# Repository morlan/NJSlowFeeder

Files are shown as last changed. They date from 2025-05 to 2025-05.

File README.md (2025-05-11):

# NJSlowFeeder

This is a slowfeeder for feeding coffee beans into a grinder. It is designed to be 3D printed and assembled with basic mechanical and electrical tools (hex driver, soldering iron, wire strippers).

## Updates:
V1.2 is out. See Issues for additional adaptors or to request additional functionality.\
Development is actively occuring, the main discussion channel is on the Gaggiuino Discord. 

## V1.2
V1.2 introduces a microcontroller (with BLE/Wifi), PWM motor controller, and load cell compatiblity while maintaining the great battery life of V1.1.\
V1.2 CAD is stable. See Issues to request new adaptors or other features.\
V1.2 Code is very much a proof of concept, and under development.\
BOM at [this link](https://docs.google.com/spreadsheets/d/11zUR7dkBkgdKcGbynbE2zPVb8PsdSGaQEwi6_OAgMBY/edit?usp=sharing).
### Demo Video
SlowFeeder V1.2 Demo (https://www.youtube.com/watch?v=54PZubX1fOw)

### Working Functions:
1. Variable speed control (hold up/down once wheel is turning)
2. On/Off control of wheel
3. Loadcell reading and setup taring (basic)
4. Deepsleep (works, but currently higher draw than expected with the HX711 for some reason)

### Planned Functions:
- [ ] WebUI for parameter control
- [ ] PoopCode :tm: - Precise single dosing of beans (for filling vials or grinding)

### Getting Started with V1.2 Code
1. Install VSCode
2. Clone this repo
3. Open the NJSlowfeeder.code-workspace file
   - This should install all required dependencies
4. Open folder in Platformio extension (if not already selected)
5. Choose the MCU you have in the Platformio Project Tasks section, plug MCU into computer, click upload
   - If this fails, try holding the boot button as you plug the MCU into the computer
6. Done

## V1.1 
V1.1 uses a fully analog approach to slowfeeding and does not include a microcontroller.\
V1.1 is unlikely to receive further updates. An analog V1.2 can be made with some tweaks to the BOM.\
Speed is set using a regulator of user choice (good options listed in BOM) and is not easily adjustable on the fly. \
See the V1.1 folder in CAD_Models for more details.\
BOM at [this link](https://docs.google.com/spreadsheets/d/11zUR7dkBkgdKcGbynbE2zPVb8PsdSGaQEwi6_OAgMBY/edit?usp=sharing).

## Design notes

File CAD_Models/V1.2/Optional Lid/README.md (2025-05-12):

# Lid

A more integrated lid is planned for release in V1.2.x or V1.3. Currently, the V1.1 version from discord user mor_177012 can be used.

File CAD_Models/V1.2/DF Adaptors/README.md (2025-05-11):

# DF Compatibility
By grinder, (XXmm) shows ID or OD dimension of feature.\
Recommended to measure your grinder, especially if it's not listed or you're unsure.\
See DFModelsImage.png for a visual list of all DF models.

## DF83
DF83V with bellows (70mm) or popcorn ring (56mm) - DF83Vring_v1_2

## DF64
There are a lot of variants of the DF64. If yours isn't listed, please contribute an image in an issue with the measurement so it can be added.\
DF64 with popcorn ring (56mm) - DF83Vring_V1_2\
DF64 without bellows or anti-popcorn ring (76mm) - DF64nopop_ring_v1_2\
DF64 Gen 2 with popcorn ring (56mm) - DF83Vring_V1_2\
DF64V V1 with bellows (56mm) - DF54Ring_V1_2

## DF54
DF54 with bellows (56mm) - DF54Ring_v1_2\
DF54 with popcorn ring (56mm) - DF83Vring_v1_2\
Note: you cannot use a DF54 with both bellows and popcorn ring since they're the same dimension.

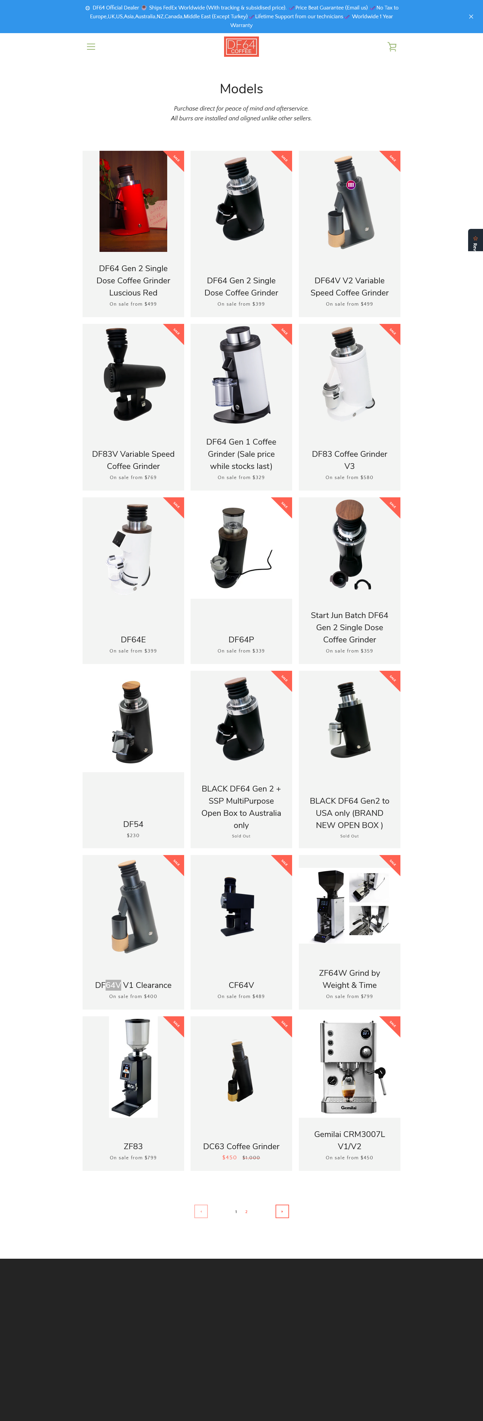
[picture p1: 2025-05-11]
CAD_Models/V1.2/DF Adaptors/DFModelsImage.png

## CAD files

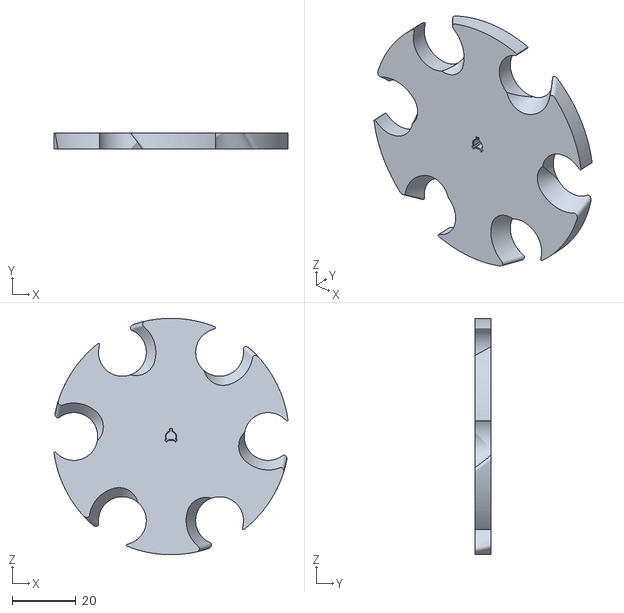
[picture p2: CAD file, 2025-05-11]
CAD_Models/V1.2/Alternate Wheels/slowfeed_wheel_6hole_nj_v1_2_.stl
73.5 x 5.00 x 74.2

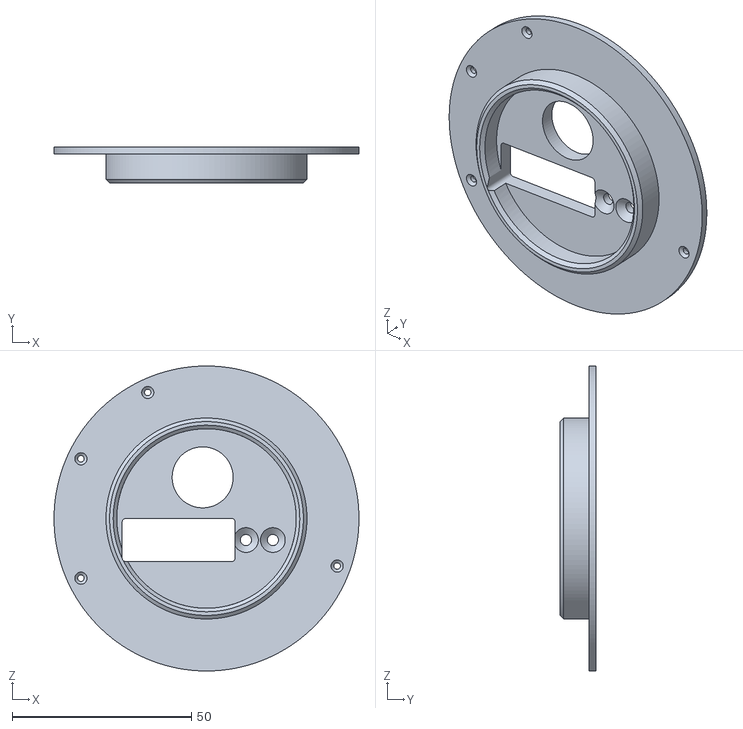
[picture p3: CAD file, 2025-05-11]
CAD_Models/V1.2/DF Adaptors/slowfeed_df54ring_bellows_v1_2.stl
85.0 x 10.0 x 85.0

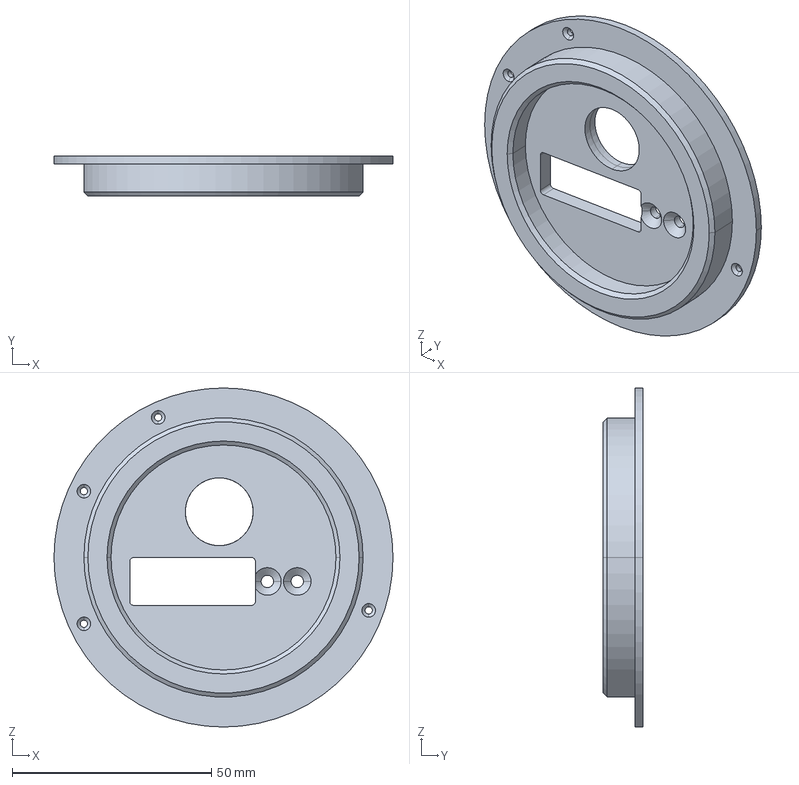
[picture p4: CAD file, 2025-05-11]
CAD_Models/V1.2/Generic Adaptor Ring (step file)/slowfeed_df83vring_v1_2.stp
85.0 x 10.0 x 85.0 mm

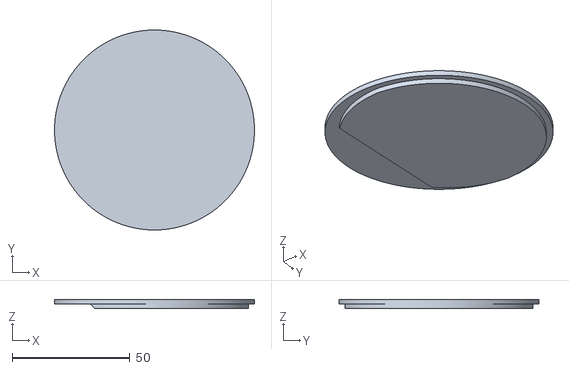
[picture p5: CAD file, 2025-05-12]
CAD_Models/V1.2/Optional Lid/slowfeed_nj_v1_1_lid_mor.stl
85.0 x 84.9 x 4.00

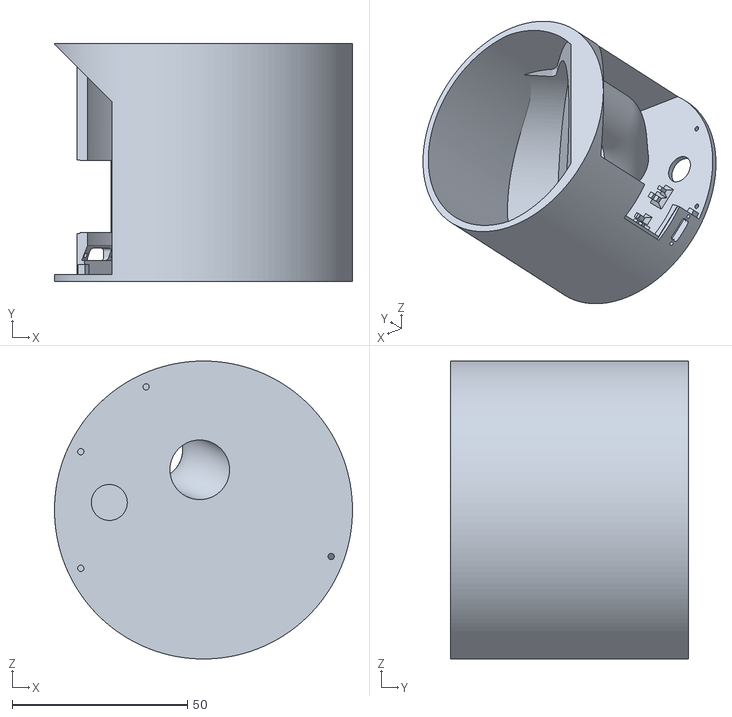
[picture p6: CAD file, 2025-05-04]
CAD_Models/V1.2/slowfeed_nj_v1_2_xiao.stl
85.0 x 68.0 x 85.0

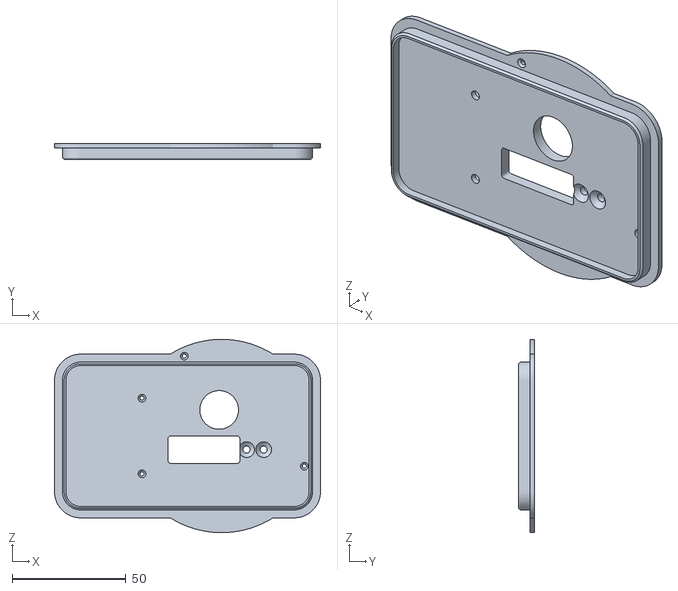
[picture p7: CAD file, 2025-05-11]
CAD_Models/V1.2/Timemore Adaptors/slowfeed_064s_ring_v1_2.stl
117.0 x 7.00 x 85.0

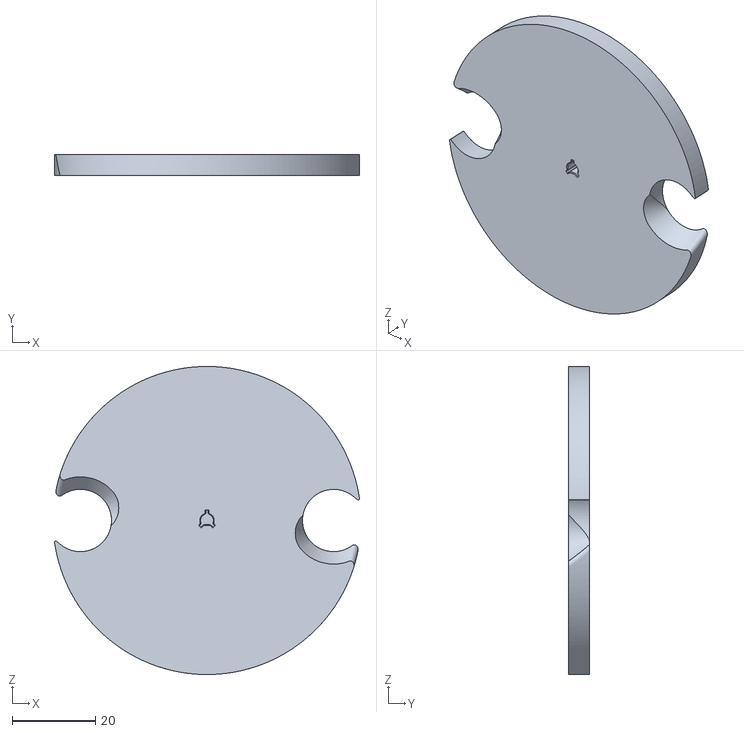
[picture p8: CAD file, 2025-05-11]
CAD_Models/V1.2/Alternate Wheels/slowfeed_wheel_2hole_nj_v1_2_.stl
73.5 x 5.00 x 74.2

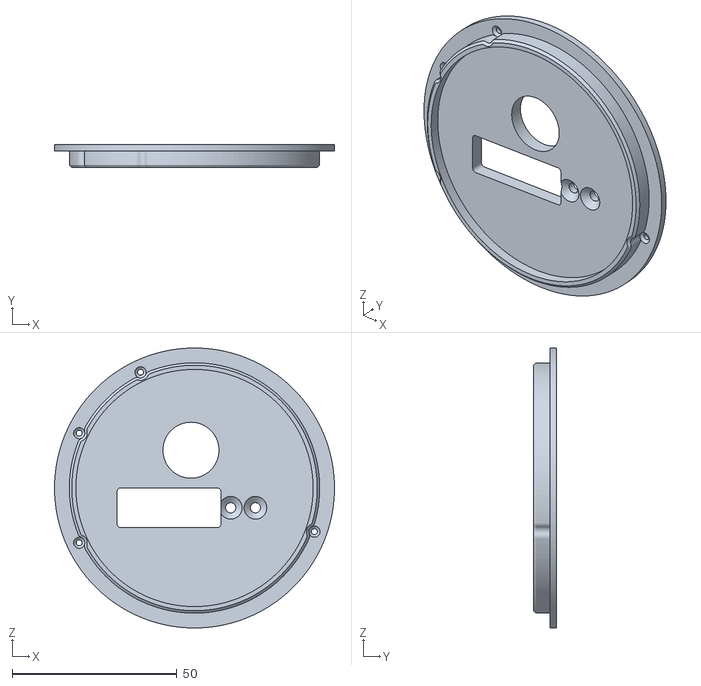
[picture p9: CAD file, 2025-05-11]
CAD_Models/V1.2/DF Adaptors/slowfeed_df64nopop_ring_v1_2.stl
85.0 x 7.00 x 85.0

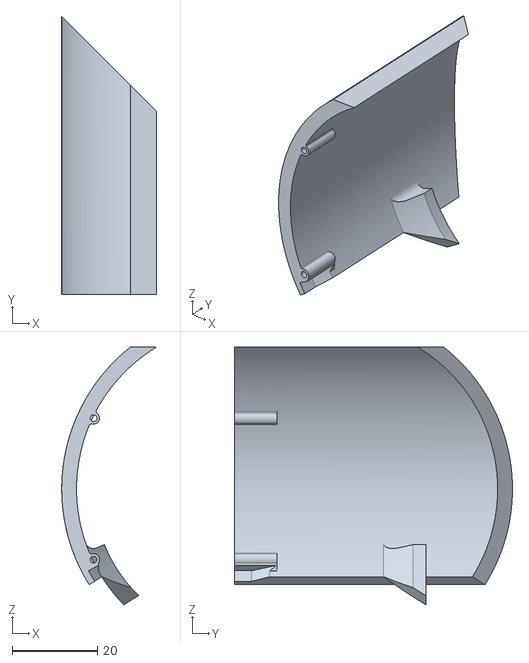
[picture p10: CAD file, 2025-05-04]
CAD_Models/V1.2/slowfeed_door_nj_v1_2.stl
22.3 x 65.4 x 60.6

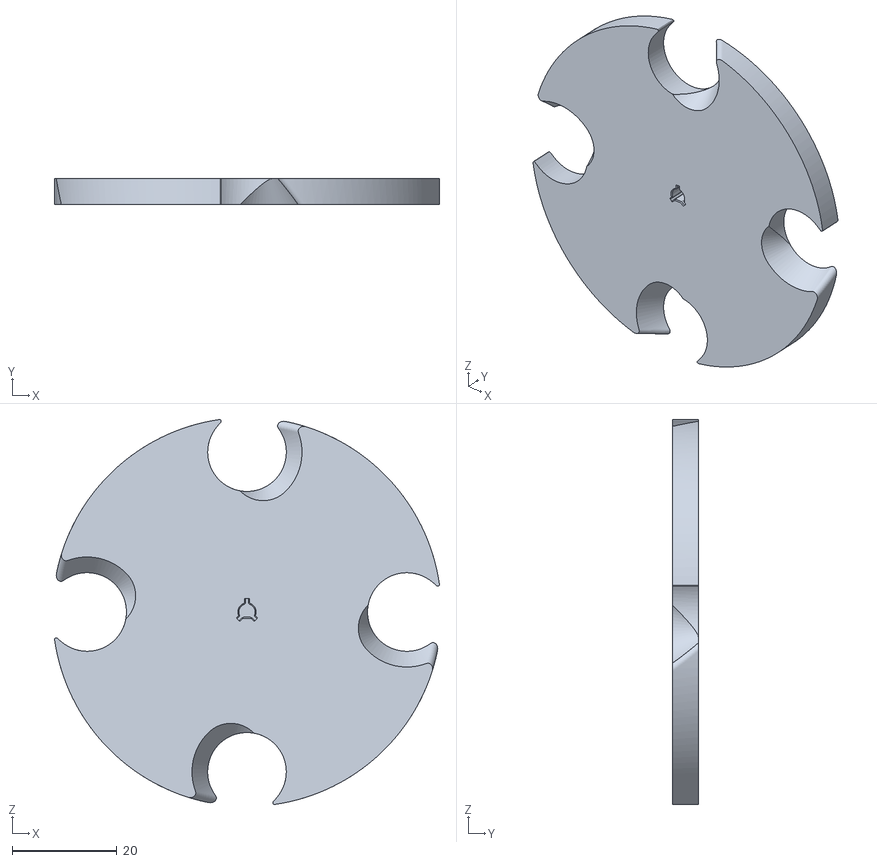
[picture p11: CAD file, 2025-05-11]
CAD_Models/V1.2/Alternate Wheels/slowfeed_wheel_4hole_nj_v1_2_.stl
73.5 x 5.00 x 73.5

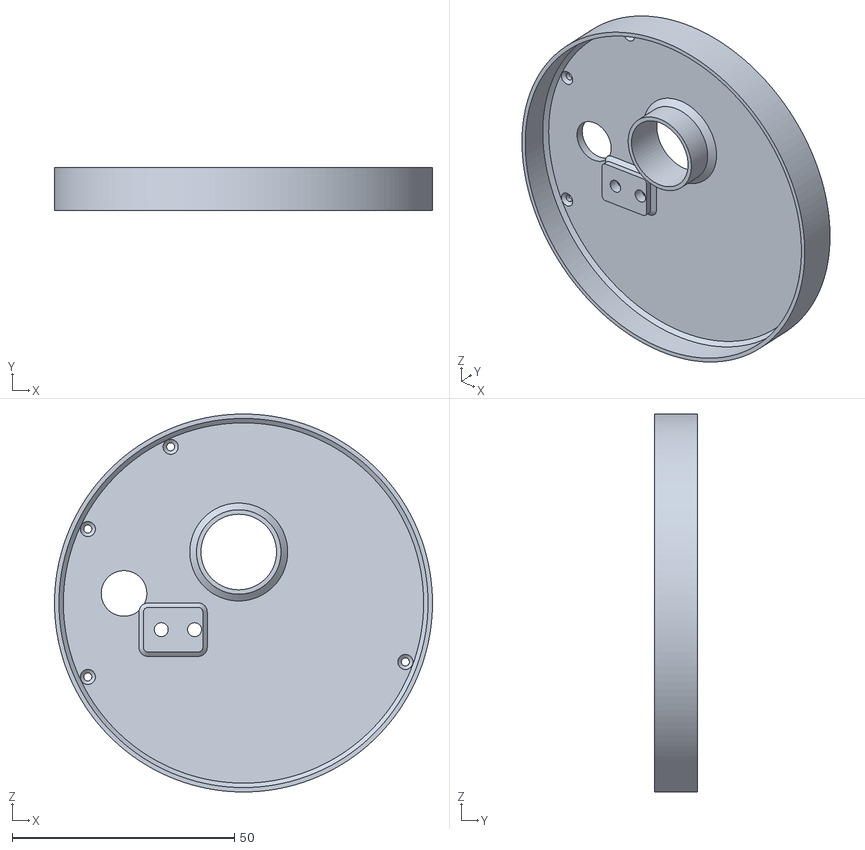
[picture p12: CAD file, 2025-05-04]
CAD_Models/V1.2/slowfeed_loadcellring_v1_2.stl
85.0 x 9.75 x 85.0

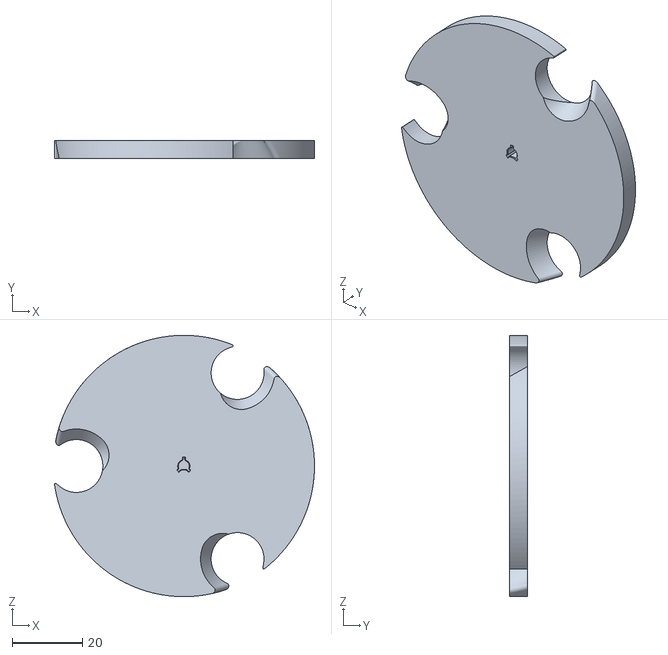
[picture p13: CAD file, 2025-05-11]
CAD_Models/V1.2/Alternate Wheels/slowfeed_wheel_3hole_nj_v1_2_.stl
73.8 x 5.00 x 74.2

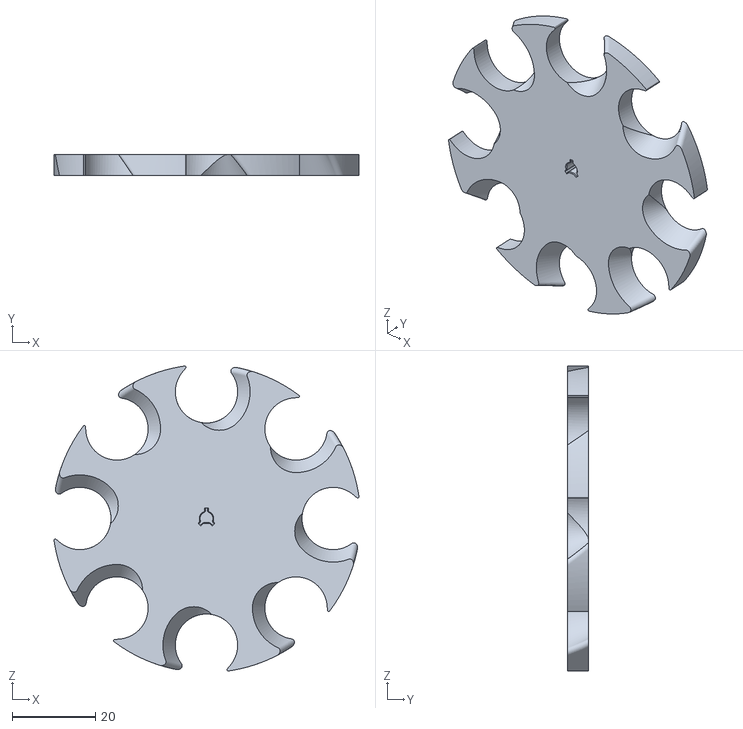
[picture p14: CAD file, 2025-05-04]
CAD_Models/V1.2/slowfeed_wheel_8hole_nj_v1_2.stl
73.5 x 5.00 x 73.5

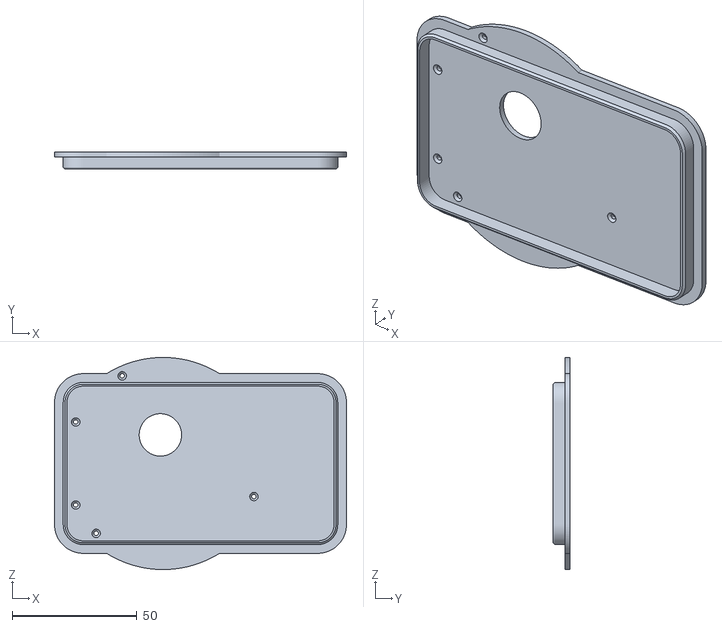
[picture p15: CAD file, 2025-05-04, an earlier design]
CAD_Models/V1.1/064S Adapters/slowfeed_v1_1_064s_ring_Back_40.stl
117.0 x 7.00 x 85.0

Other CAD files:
CAD_Models/V1.2/Varia Adaptors/slowfeed_variavs3_ring_v1_2.stl
CAD_Models/V1.2/DF Adaptors/slowfeed_df83vring_v1_2.stl
CAD_Models/V1.2/slowfeed_nj_v1_2_supermini.stl
CAD_Models/V1.1/DF Adapters/slowfeed_v1_1_df_54_64_83_ring.stl
CAD_Models/V1.1/064S Adapters/slowfeed_v1_1_064s_ring_Central.stl
CAD_Models/V1.1/064S Adapters/slowfeed_v1_1_064s_ring_Front.stl
CAD_Models/V1.1/DF Adapters/slowfeed_v_1_df64nopop_ring.stl
CAD_Models/V1.1/Door Variants/slowfeed_door_nj_v1_1_nousbC.stl
CAD_Models/V1.1/Generic Adapter STEP/slowfeed_v1_1_df83vring.stp
CAD_Models/V1.1/Varia_VS3 Adapters/slowfeed_v1_1_variavs3_ring.stl
CAD_Models/V1.1/Varia_VS3 Adapters/slowfeed_v1_1_variavs3_stabilizers_ring.stl
CAD_Models/V1.1/Wheel Variants/slowfeed_wheel_nj_2Hole_Rev1_1.stl
CAD_Models/V1.1/Wheel Variants/slowfeed_wheel_nj_3Hole_Rev1_1.stl
CAD_Models/V1.1/Wheel Variants/slowfeed_wheel_nj_4Hole_Rev1_1.stl
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

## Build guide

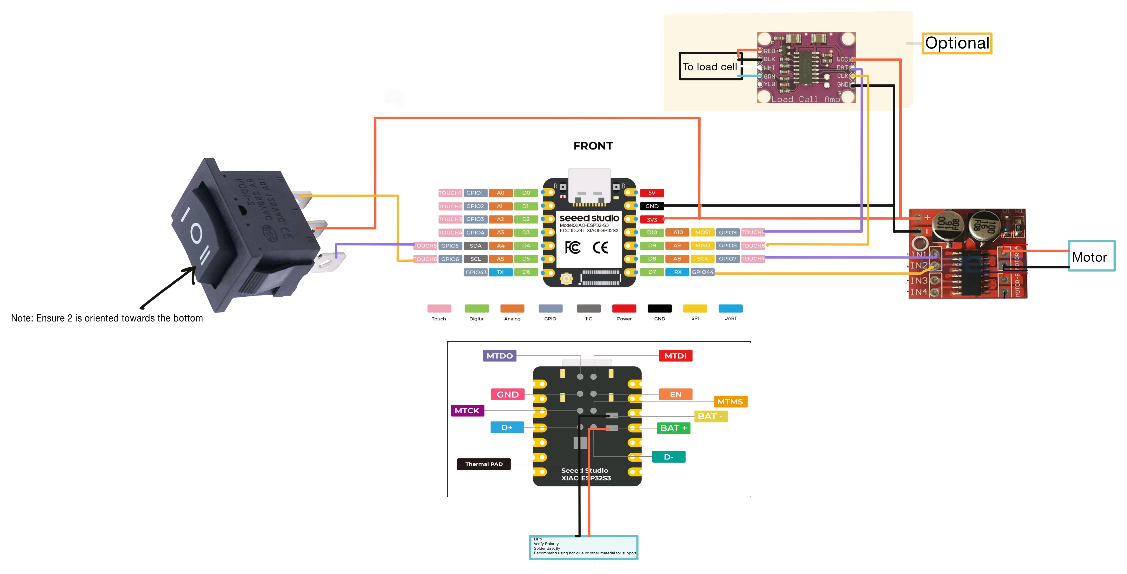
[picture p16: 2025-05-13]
CAD_Models/V1.2/Wiring Diagram Xiao-s3.JPG

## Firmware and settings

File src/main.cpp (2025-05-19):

#include <Arduino.h>
#include <Button.h> //uh, buttons
#include "driver/rtc_io.h" //deepsleep
#include "hx711.h" //loadcell

//deepsleep/wake defines, using EXT0 cause internal pullup power domain is needed.
#define BUTTON_PIN_BITMASK(GPIO) (1ULL << GPIO)  // 2 ^ GPIO_NUMBER in hex
#define WAKEUP_GPIO              GPIO_NUM_5     // Only RTC IO are allowed

// //GPIOs for R&D Supermini, don't use.
// const int IN1MotorPin = 13; //change to 12 if motor runs in reverse
// const int IN2MotorPin = 12; //change to 13 if motor runs in reverse
// const int buttonUPpin = 5;
// const int buttonDOWNpin = 4; 
// const int HX_DOUT = 10; //hx711
// const int HX_CLK = 11; //hx711
// #define HX711CLK GPIO_NUM_11 //define HX_CLK this way as well for deepsleep pullup (hx711 in sleep)


//GPIOs (note these don't match up with the silkscreen digital callouts on the XIAO board, see schematic)
const int IN1MotorPin = 44; //change to 44 if motor runs in reverse
const int IN2MotorPin = 7; //change to 7 if motor runs in reverse
const int buttonUPpin = 5; //labeled as D4 on the silkscreen for xiao
const int buttonDOWNpin = 6; //labeled as D5 on the slikscreen for xiao
const int HX_DOUT = 9; //hx711, labeled as D10 on the silkscreen for xiao
const int HX_CLK = 8; //hx711, labeled as D9 on the silkscreen for xiao
#define HX711CLK GPIO_NUM_8 //define HX_CLK this way as well for deepsleep pullup (hx711 in sleep)

//motor variables

float MotorVoltage = 0;  //Current value of Motor Drive Voltage
  //user config
int MotorPWMFrequency = 20000; //motor PWM frequency, 20000 you can't hear, 1000 has more granular range.
float MotorStartVoltage = 2.4; //voltage the system will default to when clicking or holding up. Use 1.5V for 1000Hz analog freq, 2.7 for 20000Hz.
float BusVoltage = 3.3; //PWM Logic Level
float MotorVoltageStep = 0.1; //voltage the motor will step up per MotorUpdateTime interval when a button is held  Use 0.2 for 1000Hz, 0.1 for 20000Hz
int MotorUpdateTime = 500; //milliseconds, controls how frequently the motor voltage gets updated

int setMotorVoltage(int, float, float);

//Loop/Sleep Variables
u_long PrevUpdateTime = 0; 
u_long SleepTimeoutTracker = 0;
  //user config
int SleepTimeoutTime = 60000; //milliseconds, controls how long before device deep sleep when there's no weight, button presses, etc.
int SleepErrorTimeoutTime = 120000;  //sleep regardless of weight after 5 minutes of no button pushes. Used to cover for any weird scale behavior.
float WeightTimeoutMinimumBound = 2.0; //minimum weight to stay awake
float WeightTimeoutMaxiumumBound = 30.0; //maximum bean weight expected in slowfeeder, keeps awake.

//MotorAutoOff
u_long MotorRunTime = 0;
int MotorRunTimeout = 10000; //milliseconds to run motor without beans
float MotorTimeoutWeightMinimum = 1.0; //minimum weight before motor auto-off routine begins evaluating

//LastButtonPress
u_long LastButtonPress = 0;
int ButtonRunTimeout = 5000; //milliseconds to ignore motor shutoff conditions due to button press

//HX711 Scale
HX711 scale;
float calibration_factor = 2182; //put in your calibration factor from calibration code
float scale_reading = 0;

//Button configs
Button buttonUP = Button(buttonUPpin, BUTTON_PULLDOWN, true, 50);
Button buttonDOWN = Button(buttonDOWNpin, BUTTON_PULLDOWN, true, 50);
//Button Callbacks
// void onPress(Button& b){
// 	Serial.print("onPress: ");
// 	Serial.println(b.pin);
// 	//digitalWrite(13,HIGH);
// }

// void onClick(Button& b){
// 	Serial.print("onClick: ");
// 	Serial.println(b.pin);
// 	//digitalWrite(13,HIGH);
// }

void onRelease(Button& b){
	Serial.print("onRelease: ");
	Serial.println(b.pin);
	if(b.buttonstatus == 0){
    Serial.print("Click: ");
   	Serial.println(b.pin);
    b.buttonstatus = 2;
  }
  else if(b.buttonstatus == 1){
    Serial.print("HoldRelease: ");
   	Serial.println(b.pin);
    b.buttonstatus = 0;
  }
  
  else {
    Serial.print("Unhandled pin triggered - release");
    Serial.println(b.buttonstatus);
  }
}

void onHold(Button& b){
	Serial.print("Held: ");
	Serial.println(b.pin);
  b.buttonstatus = 1;
  
}

//deepsleep related
/*
  Method to print the reason by which ESP32
  has been awaken from sleep
*/
void print_wakeup_reason() {
  esp_sleep_wakeup_cause_t wakeup_reason;

  wakeup_reason = esp_sleep_get_wakeup_cause();

  switch (wakeup_reason) {
    case ESP_SLEEP_WAKEUP_EXT0:     Serial.println("Wakeup caused by external signal using RTC_IO"); break;
    case ESP_SLEEP_WAKEUP_EXT1:     Serial.println("Wakeup caused by external signal using RTC_CNTL"); break;
    case ESP_SLEEP_WAKEUP_TIMER:    Serial.println("Wakeup caused by timer"); break;
    case ESP_SLEEP_WAKEUP_TOUCHPAD: Serial.println("Wakeup caused by touchpad"); break;
    case ESP_SLEEP_WAKEUP_ULP:      Serial.println("Wakeup caused by ULP program"); break;
    default:                        Serial.printf("Wakeup was not caused by deep sleep: %d\n", wakeup_reason); break;
  }
}


void beep(int count) {
  //spin motor to beep
  setMotorVoltage(IN1MotorPin, BusVoltage, 0); 

  analogWriteFrequency(1000);

  do {
    delay(250);
    setMotorVoltage(IN1MotorPin, BusVoltage, 0.5); 
    delay(250);
    setMotorVoltage(IN1MotorPin, BusVoltage, 0); 
  } while (--count);
  
  analogWriteFrequency(MotorPWMFrequency);
}


void setup() {
  //motor configs
  pinMode(IN1MotorPin, OUTPUT);
  analogWriteFrequency(MotorPWMFrequency); //20000 is out of hearing range, 1000 seems to be fine with the motor controller in the housing.
  pinMode(IN2MotorPin, OUTPUT);
  analogWrite(IN2MotorPin, 0);

  //start serial for ButtonDebug
  Serial.begin(115200);
  Serial.println("Serial Start");

  print_wakeup_reason();

  //start scale
  scale.begin(HX_DOUT, HX_CLK);
  scale.set_scale(calibration_factor);
  scale.tare(); //assume no beans present in slow feeder when turned on. Alternatively, can experiement with zero factor below.
  

  // Assign callback functions
  //buttonUP.pressHandler(onPress);
  //buttonUP.clickHandler(onClick);
  buttonUP.releaseHandler(onRelease);
  buttonUP.holdHandler(onHold, 1000); // must be held for at least 1000 ms to trigger

  //buttonDOWN.pressHandler(onPress);
  //buttonDOWN.clickHandler(onClick);
  buttonDOWN.releaseHandler(onRelease);
  buttonDOWN.holdHandler(onHold, 1000); // must be held for at least 1000 ms to trigger
  
  
  //Methods to prevent scale taring before button release. Might be worth pairing with zero factor to create robust detection of unit resting on a counter.
  Serial.println(digitalRead(buttonUPpin));
  Serial.println(digitalRead(buttonDOWNpin));
  while(digitalRead(buttonUPpin) != LOW || digitalRead(buttonDOWNpin) != LOW){ 
    delay(500);
    Serial.println("Button pressed, delay startup tare");
  } 
  //delay for 2 second to allow for time to set the slowfeeder on the counter.
  Serial.println("Start Delay startup");
  delay(2000);
  Serial.println("End Delay Startup");
  scale.tare();
  //spin motor to indicate completion of startup
  analogWriteFrequency(1000);
  setMotorVoltage(IN1MotorPin, BusVoltage, 0.5); 
  delay(500);
  setMotorVoltage(IN1MotorPin, BusVoltage, 0);
  analogWriteFrequency(MotorPWMFrequency);
  //reset status, button lib has startup bugs - will always trigger a release and click mode per button when process is called the first time. Also cover button pressed reset from scale method
  buttonUP.process();
  buttonDOWN.process();
  buttonUP.buttonstatus = 0;
  buttonDOWN.buttonstatus = 0;
  Serial.println(buttonUP.buttonstatus);
  Serial.println(buttonDOWN.buttonstatus);

  //set time trackers to current time
  PrevUpdateTime = millis();
  SleepTimeoutTracker = PrevUpdateTime;
}


void loop() {
  int updatetimebool = ((millis() - PrevUpdateTime) > MotorUpdateTime);
  if(((millis() - SleepTimeoutTracker) > SleepTimeoutTime) || ((millis() - LastButtonPress) > SleepErrorTimeoutTime)){
      //spin motor 3x to indicate sleep
      beep(3);

      //put HX711 to sleep
      rtc_gpio_pulldown_dis(HX711CLK);
      rtc_gpio_pullup_en(HX711CLK);
      //begin going to sleep :)
      esp_sleep_enable_ext0_wakeup(WAKEUP_GPIO, 1);  //1 = High, 0 = Low
      // Configure pullup/downs via RTCIO to tie wakeup pins to inactive level during deepsleep.
      rtc_gpio_pullup_dis(WAKEUP_GPIO);
      rtc_gpio_pulldown_en(WAKEUP_GPIO);
      Serial.println("Going to sleep now");
      esp_deep_sleep_start();
      Serial.println("If you see this, no you didn't");
  }
  if(updatetimebool){
    //read scale every motor update interval
    scale_reading = scale.get_units();
    Serial.println(scale_reading, 1);
  }
  //check button states
  buttonUP.process();
  buttonDOWN.process();
  
  //time state evaluations
  if(buttonUP.buttonstatus != 0 || buttonDOWN.buttonstatus != 0){ LastButtonPress = millis();} //track last button active time
  if(buttonUP.buttonstatus != 0 || buttonDOWN.buttonstatus != 0 || (scale_reading > WeightTimeoutMinimumBound && scale_reading < WeightTimeoutMaxiumumBound)){ SleepTimeoutTracker = millis();} //delay sleep
  
  //button status evaluations
  if(buttonUP.buttonstatus == 1){
    //do hold things
    //Serial.println("holdUP");
    if(updatetimebool){
      if(MotorVoltage == 0){MotorVoltage = MotorStartVoltage;}
      MotorVoltage = constrain(MotorVoltage + MotorVoltageStep, 0, BusVoltage);
      Serial.print("MotorVoltage: ");
      Serial.println(MotorVoltage, 2);
      setMotorVoltage(IN1MotorPin, BusVoltage, MotorVoltage);
    }
  }
  else if(buttonUP.buttonstatus == 2){
    //do click things
    //Serial.println("clickUP");
    if(MotorVoltage == 0){ //sets motor voltage to start voltage
      setMotorVoltage(IN1MotorPin, BusVoltage, MotorVoltage = MotorStartVoltage);
    } else { //sets motor voltage to current user set voltage
      setMotorVoltage(IN1MotorPin, BusVoltage, MotorVoltage);
    }
    //reset buttonUP state
    buttonUP.buttonstatus = 0;
  }

  if(buttonDOWN.buttonstatus == 1){
    //do hold things
    //Serial.println("holdDOWN");
    if(updatetimebool){
      MotorVoltage = constrain(MotorVoltage - MotorVoltageStep, 0, BusVoltage);
      Serial.print("MotorVoltage: ");
      Serial.println(MotorVoltage, 2);
      setMotorVoltage(IN1MotorPin, BusVoltage, MotorVoltage);
    }
  }
  else if(buttonDOWN.buttonstatus == 2){
    //do click things
    //Serial.print("clickDOWN");
    if(MotorVoltage == 0){ //manually tare scale 
      delay(2000);
      scale.tare();
    } else {
      setMotorVoltage(IN1MotorPin, BusVoltage, 0);
    }
    //reset buttonDOWN state
    buttonDOWN.buttonstatus = 0;
  }
  
  //Motor auto-off feature
  if(MotorVoltage > 0 && scale_reading < MotorTimeoutWeightMinimum && MotorRunTime == 0){
    MotorRunTime = millis();
  }
  else if(MotorVoltage > 0 && scale_reading < 1.0 && MotorRunTime > 0){
    if((millis() - MotorRunTime > MotorRunTimeout) && (millis()-LastButtonPress > ButtonRunTimeout)){
      setMotorVoltage(IN1MotorPin, BusVoltage, MotorVoltage = 0);

      //spin motor 2x to indicate motor timeout
      beep(2);    

      Serial.println("No Load Motor Timeout");
    }
  }
  else{
    MotorRunTime = 0;
  }

  if(updatetimebool){
    PrevUpdateTime = millis();
  }
  delay(10);
}

int setMotorVoltage(int driverPin, float BusVoltage, float MotorVoltage) {
  if(MotorVoltage > BusVoltage){return 1;}
  else{
    int setpoint = (int)((MotorVoltage / BusVoltage) * 255);
    analogWrite(driverPin, setpoint);
    return 0;
  }
}

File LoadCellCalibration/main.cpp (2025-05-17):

/*
 Example using the SparkFun HX711 breakout board with a scale
 By: Nathan Seidle
 SparkFun Electronics
 Date: November 19th, 2014
 License: This code is public domain but you buy me a beer if you use this and we meet someday (Beerware license).
 
 This is the calibration sketch. Use it to determine the calibration_factor that the main example uses. It also
 outputs the zero_factor useful for projects that have a permanent mass on the scale in between power cycles.
 
 Setup your scale and start the sketch WITHOUT a weight on the scale
 Once readings are displayed place the weight on the scale
 Press +/- or a/z to adjust the calibration_factor until the output readings match the known weight
 Use this calibration_factor on the example sketch
 
 This example assumes pounds (lbs). If you prefer kilograms, change the Serial.print(" lbs"); line to kg. The
 calibration factor will be significantly different but it will be linearly related to lbs (1 lbs = 0.453592 kg).
 
 Your calibration factor may be very positive or very negative. It all depends on the setup of your scale system
 and the direction the sensors deflect from zero state

 This example code uses bogde's excellent library: https://github.com/bogde/HX711
 bogde's library is released under a GNU GENERAL PUBLIC LICENSE

 Arduino pin 2 -> HX711 CLK
 3 -> DOUT
 5V -> VCC
 GND -> GND
 
 Most any pin on the Arduino Uno will be compatible with DOUT/CLK.
 
 The HX711 board can be powered from 2.7V to 5V so the Arduino 5V power should be fine.
 
*/
#include <Arduino.h>
#include "HX711.h"

const int DOUT = 9; //hx711, labeled as D10 on the silkscreen for xiao
const int CLK = 8; //hx711, labeled as D9 on the silkscreen for xiao

HX711 scale;

float calibration_factor = -2650; //- njscale1, zero factor ~-340528

void setup() {
  Serial.begin(9600);
  Serial.println("HX711 calibration sketch");
  Serial.println("Remove all weight from scale");
  Serial.println("After readings begin, place known weight on scale");
  Serial.println("Press + or a to increase calibration factor");
  Serial.println("Press - or z to decrease calibration factor");
  scale.begin(DOUT,CLK);
  scale.set_scale();
  scale.tare();	//Reset the scale to 0

  long zero_factor = scale.read_average(); //Get a baseline reading
  Serial.print("Zero factor: "); //This can be used to remove the need to tare the scale. Useful in permanent scale projects.
  Serial.println(zero_factor);
}

void loop() {

  scale.set_scale(calibration_factor); //Adjust to this calibration factor

  Serial.print("Reading: ");
  Serial.print(scale.get_units(), 1);
  Serial.print(" g"); //Change this to kg and re-adjust the calibration factor if you follow SI units like a sane person
  Serial.print(" calibration_factor: ");
  Serial.print(calibration_factor);
  Serial.println();

  if(Serial.available())
  {
    char temp = Serial.read();
    if(temp == '+' || temp == 'a')
      calibration_factor += 10;
    else if(temp == '-' || temp == 'z')
      calibration_factor -= 10;
    else if(temp == '*')
      scale.tare();
  }
  delay(10);
}

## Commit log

2025-04-13 Working Switches, need softstart
2025-05-04 Update sleep logic to avoid edge case
    [main.cpp]
2025-05-04 V1.1 CAD Files
    [slowfeed_door_nj_v1_1.stl, slowfeed_door_nj_v1_1_nousbC.stl, slowfeed_nj_v1_1.stl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]
2025-05-04 V1.2 Initial Release!
    [slowfeed_df83vring_v1_2.stl, slowfeed_door_nj_v1_2.stl, slowfeed_loadcellring_v1_2.stl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]
2025-05-11 Addititional adaptors from V1.1 with loadcell compatiblity
    [slowfeed_064s_ring_v1_2.stl, slowfeed_df64nopop_ring_v1_2.stl, slowfeed_variavs3_ring_v1_2.stl]
2025-05-11 add step adaptor ring for user modification
    [slowfeed_df83vring_v1_2.stp]
2025-05-11 add alternate wheels
    [slowfeed_wheel_2hole_nj_v1_2_.stl, slowfeed_wheel_3hole_nj_v1_2_.stl, slowfeed_wheel_4hole_nj_v1_2_.stl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]
2025-05-11 DF54 adaptor, DF readme
    [slowfeed_df54ring_bellows_v1_2.stl]
2025-05-12 Add v1.1 lid
    [slowfeed_nj_v1_1_lid_mor.stl]
2025-05-13 Add wiring diagram
2025-05-13 pin updates for xiao
2025-05-17 Fixed GPIOs cause SEEED define is goofy
    [main.cpp]
2025-05-17 Fix logic hole
2025-05-18 Added manual tare function and fixed buttonUP motor voltage logic to use current set voltage
    [main.cpp]
2025-05-18 Tie IN2 low for motor driver operation on xiao
2025-05-19 Added beep function and tones to indicate motor timeout and sleep
